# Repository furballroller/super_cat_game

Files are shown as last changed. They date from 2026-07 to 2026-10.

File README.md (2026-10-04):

# super_cat_game

> [!CAUTION]
> The current hardware version is [hardware_v1](hardware_v1)!! Anyway, is my first PCB project, so neither version is very good. It may be cost-inefficient and buggy.

> [!WARNING]
> **if regenerating production files from KICAD, the LCSC Part # in the BOM and component orientations in CPL may be incorrect. Make sure to double check part numbers and orientation in JLCPCB before paying** I don't know how to fix it and had to directly edit BOM.csv :<

> [!TIP]
> these banners are so cool lol

_Final product:_

- [_3D-printed case on Onshape_](https://cad.onshape.com/documents/4ded436d6b7f683e9c68b6fa/w/fe5cc562122e090332767be7/e/b2ba9b935da609d900851709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) (proper assembly instructions below)
- [_KiCAD Project_](hardware_v1)
- [_Arduino Sketches_](software) (PlatformIO IDE)

A5 - 1 (1)

Cat silhouette traced from this photo: ID <a href="https://www.dreamstime.com/cat-mid-air-jump-white-coloured-patches-jumping-down-against-yellow-wall-image115652480">115652480</a> @ <a href="https://www.dreamstime.com/lazaroctavian_info">Octavian Mihai Lazar</a> | <a href="https://www.dreamstime.com/">Dreamstime.com</a>

## backstory

So basically my friend had a cat, and I was just getting into arduino electronics, so I wanted to make a chasing game for the both of them! I ended up deciding on a pressure-sensitive LED mat, for an interactive laser-pointer kind-of game, with wifi connectivity for convenience. It could be nice to use regularly to keep your pets fit, but really this is just a fun beginner project to me.

Then, in between reels, I discovered Fallout, a 2026 hardware hackathon for 13-18yos backed by Hack Club. I was drawn in by the promise of full project funding and a free trip to Shenzhen, and was enthralled by the experienced and helpful community ready to help. I would highly recommend Hack Club hackathons like this if you're new/intermediate like me and within the age range :>

The scope expanded when I realised that there's so much more potential with my setup! I used a powerful ESP32 S3 N16R8 Devkit, so I broke out the pins for prototyping. You can hook up any peripherals you want for your game! Like, with a [3D printed kibble dispenser](https://electronoobs.com/tutorial/3d-printed-arduino-cat-feeder), you could implement scheduled feeding and dispense treats as an in-game currency :>

But you can program anything, not just for a cat! Chess online/locally would be easy and super fun! Maybe even something like [Osu](https://osu.ppy.sh/), make use of the full spectrum of colours! You might even want to host an online multiplayer game...

## overview

This project hardwires a pressure-sensitive LED mat to a powerful general-purpose devkit, intended for making inuitive arcade-style games (for a cat, if you'd like! :> )

I used Arduino to code up a simple cat game ([Arduino sketch](software/cat_game)), where a laser dot darts around, avoids people, and resets the game when caught. To use this, just upload the code to the devkit (using it's built-in USB-C port), plug it into the PCB, then plug the PCB into the wall!

The devkit opens the project to endless posibilities, including bluetooth game controllers, network games, and over-the-air coding for easy game dev ([template Arduino sketch with ArduinoOTA](software/template+OTA)). This project is meant to function as a very cool extension of the microcontroller, for those who might want to jump straight into making games using this touch interface.

### specs

- ~45*45cm play area
  - 14*14 Velostat pressure sensor matrix
  - 13*13 WS2812B LED matrix (very low resolution tho)
- Wifi/Bluetooth capability
  - Cheap ESP32 S3 N16R8 Devkit clone off [AliExpress](https://www.aliexpress.com/item/1005008790513258.html)
- Broken-out devkit pins and 5V power supply for any peripherals you might like to add
  - e.g. [3D printed kibble dispenser](https://electronoobs.com/tutorial/3d-printed-arduino-cat-feeder)

### cost

[Overall BOM.csv](bom.csv) | [PCB BOM.csv](hardware_v1/production/bom.csv)

The overall BOM represents what I plan to order: 5 populated PCB boards (JLCPCB minimum order quantity), but only 1 housing/mat/devkit. Though, I did include a laptop charger and the LED strips that I already have. This comes out to 111.83 USD.

I didn't include tools (not consumed) like soldering equipment and a 3D printer, but I did approximate the cost of consumables like solder, tape rolls, screws and filament.

#### Per unit

|Cost (USD)|Stuff|
|--|--|
|14.11|Power supply|
|22.15|Electronics|
|2.32|Housing|
|33.32|Mat|

Excluding shipping, it's about 71.90 USD per unit.

<!--
## big_picture
the mat should roll up

-->

### hardware

<!-- a flowchart -->


I decided to use a USBC PD laptop charger as the PSU since it's quite common and versatile and it's not too expensive.

The velostat matrix is connected with two 45cm lengths of 16-way IDC cables (not shown in CAD). One individual line will be cut, stripped, and stuck to the sensor lines at regular intervals along the mat, 14 horizontally and 14 vertically. There's more detail in the assembly walkthrough below.

#### Velostat pressure sensor matrix

The rest of the system is quite self-explanatory except for the Velostat pressure sensor matrix, so I'll try my best to explain. There's a good video of it by [MarcoReps on YouTube](https://www.youtube.com/watch?v=0uPZwMg5B3k).

Velostat is a thin plastic sheet with electrical resistance that decreases as it is pressed or deformed.

Each "sensor" works by sandwiching a square of Velostat between perpendicular strips of conductive fabric tape, such that it acts as a resistor between them.

velostat sensor

When the Velostat is compressed, the resistance between the two strips decreases. Connecting one tape to 3.3V through a normal resistor (e.g. 10k Ohms) and the other to GND, the circuit becomes a voltage divider between the Velostat and the normal resistor. The microcontroller can read the voltage at this point (relative to GND) to figure out the resistance of the Velostat, which tells you approximately how much pressure is on it!

circuit

Along one long conductive strip, multiple perpendicular strips can be laid across with Velostat between, creating a line of sensors. By connecting all the perpendicular lines to a multiplexer's channels, they are all left in a high-impedance state except the selected channel. The normal resistor and ADC pin can be connected on the single output of the multiplexer, so they can be reused when the channel is switched.

Conventional diagram



Another way to show the same circuit:



The matrix in the mat is 14 conductive lines crossed with 14 perpendicular lines, making a total of 14^2=196 "sensors." It's the same as the line of sensors, but there are multiple lines of sensors, with one ground connection each. The ground connections are controlled by another multiplexer, only allowing one line to be active at once.



This is a 4 by 4 example. Multiplexer 1 picks the line of sensors connected to GND, and multiplexer 2 picks the sensor from that line to read.

The real mat works using two 16 channel multiplexers (CD74HC4067) on the PCB: the ESP32 specifies a channel, the multiplexers switch to the corresponding Velostat sensor, then the ESP32 takes a reading through it's ADC pin. Instead of the normal resistor, there is a potentiometer (variable resistor) that allows you to adjust sensitivity.



This is how the sensors are tiled

### code

[My example sketches:](software) (currently untested)

- [press_light](software/press_light): intended to be a test of function, that should simply light up LEDs around where you press. This would be great for making sure the hardware is behaving, or as a fun starting point if you want to experiment with code and get the hang of Arduino.
- [cat_game](software/cat_game): a simple cat game where the computer controls a red laser-pointer-like dot to avoid people.
- [template](software/template): an empty template for your project! I set up some useful functions in functions.cpp and put all the initialisation code in for you.
- [template+OTA](software/template+OTA): same as [template](software/template), but I also set up [ArduinoOTA](https://github.com/JAndrassy/ArduinoOTA). I think it's really cool that you can upload code wirelesly like magic! ([a cool tutorial page](https://www.programmingelectronics.com/arduinoota/))

I used PlatformIO on Visual Studio Code to write my Arduino programs for the microcontroller. This may sound convoluted, but I did it this way because Arduino programs are easy to write (compared to industrial languages) but Arduino IDE is horrible!

If you want to use Arduino IDE, you can quite easily copy-paste my code into the IDE. For a given project folder in [software](software), you just kinda paste the stuff from functions.cpp first, then the stuff from main.cpp... it may take a bit of fiddling around though, so I would recommend looking into PlatformIO (after getting used to it, I find it way way better :>)

I used [FastLED](https://github.com/fastled/fastled) to control the WS2812B neopixels

## assembly

assembly image

<!-- <img width="360" height="360" alt="image" src="https://github.com/user-attachments/assets/02625bfc-674e-4e6e-94d2-2b4add3a4ae9" />   -->

I thought it was cool to include the little thumb, and the vents are accurate too! They're like LHS/RHS prints from a cat grabbing the case or something :>
Also, the USB port is on a 45 degree angle so the wire leaves perpendicular to the mat.

I'll touch on the key features of the design below. For more info, see the 3D model for this is in [my Onshape doc](https://cad.onshape.com/documents/4ded436d6b7f683e9c68b6fa/w/fe5cc562122e090332767be7/e/b2ba9b935da609d900851709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), under the tab "boxV1"
(my bad for the bad organisation, I'm still learning CAD)  

If you want to change the tolerances (they're untested), I haven't tried, sorry if something is inaccurate. It may be best to change the tolerances in your slicer.
> [!TIP]
> the Onshape link might not work. I had to click it, then **Ctrl+X Ctrl+V Enter** from the address bar

### electronics

I contained the circuit in a PCB attached to the corner of the mat, and I've also desgined a 3D-printed housing for it.

The whole project runs off an ESP32 S3 N16R8 microcontroller devkit, which is like an Arduino but better (in my opinion)

[On Aliexpress](https://www.aliexpress.com/item/1005008790513258.html)
(**I would recommend getting "S3 KIT" because the screw terminals are very handy, but I put the board by itself into the BOM**)

When choosing a microcontroller, I noticed that a lot of clone (knockoff) ESP32 S3 devkits, including the one I bought, have the antenna port but also an antenna built into the PCB. I think they give you the option to change to an external antenna by doing a bit of soldering, but by default it is connected to the onboard antenna.

#### PCB

PCB preview
<!-- <img width="360" height="360" alt="PCB" src="" />   -->

> [!CAUTION]
>
> - Ignore the capacitor going off the edge, the EasyEDA model is wrong
> - The two parallel rows of vertical pin headers (for the devkit) should be female, again the EasyEDA model is wrong

PCB

schematic

About the design:

- JL1 and JR1 hold the ESP32 devkit
- The USB-C is for power only
- JLED1 is for the LED strip
- JPWR1 is 5V power for any peripherals you might want to add
- The IDC sockets are for the pressure-sensing data lines
- The fancy ICs are just CD74HC4067 multiplexers for selecting the pressure-sensing channel to read
- The potentiometer is for adjusting the sensitivity of the pressure sensing (it's part of a voltage divider)
- U1 is a logic level converter for the LEDs.

Regarding soldering: I designed the PCB to be hand-soldered, hence the abundance of THT and the large 0805 capacitors/resistors. My only concerns are the SSOP 74HC4067 and 6-pin USB-C port, but other than that the rest should be beginner friendly, from what I can gather. I'm thinking of going to my local makerspace to solder this. In Melbourne, Library at the Dock has one equipped with a digital microscope, flux/solder/wick, and  Hakko FX-888 soldering stations, all free of charge. Maybe be careful around ESD, I'll update on my degree of success when I build it.

#### housing

housing
<!-- <img width="412" height="319" alt="housing" src="https://github.com/user-attachments/assets/c8540786-b5d8-4412-b8d4-58c8dfad0934" /> -->

I'm not very good at 3D CAD either, but this should work... I think  
The design is quite self-explanatory, but below are some key features that I thought I should highlight:

bottom of base  

On the base, there is a cutout for those holes on the mat. The holes are truncated cones, inspired by [this video by BV3D](https://youtu.be/zaphoWIwSGI). 
I designed my case to work with 3M screws, and the truncated cones means you can use machine screws or self-tapping (I think)

top of base  
top of base, PCB overlaid  

The base supports the PCB with a few stilts through the holes in the PCB, again using M3 truncated cones. The smaller stilts give some support to the IDC connectors, which I expect may require some force to plug in and out.

top  
  

The top fits on the bottom with M3 screws, and features holes for IDC, the LED strip, the USB-C power port, optional 5V power lines, and the broken-out GPIO from the devkit. Also there are (very stylish) vents :>

lid  
  

There's also a lid that slides onto the top, so the devkit is protected but can be accessed easily during game development. 
I included a cool thinner section where the onboard LED is, so the status light should look like a cat's paw.

### sensor_mat

> [!TIP]
> You'll see two holes in the top-right corner of the mat. These fit M3 screw heads, and should help anchor the PCB to the mat.

1. The LED strips
LED strips assembled  

I used 13 LED long sections of 30 LED/m WS2812B individually addressable LEDs
With pads on either side, each section is about 43.333mm long (theoretically)  
[Similar product on AliExpress](https://www.aliexpress.com/item/1005007989207832.html)
(**MAKE SURE THE SPACING IS 30 LEDs/m; I'd recommend buying 2 "3m 30 IP30"**)

There are 13 of these sections, forming a 13*13 grid (169 LEDs)
The ends can be soldered together with jumper wires, preferably with stranded wire, like so:

<figure>
	Suggested LED strip interconnection
	Suggested fold to connect to PCB  
	<figcaption>(don't crease too much tho!)</figcaption>
</figure>

2. The popsicle sticks  

Popsicle sticks assembled  

I used 2mm thick, 18mm wide popsicle sticks (jumbo craft sticks)  
[My local option (Australia)](https://www.officeworks.com.au/shop/officeworks/p/kadink-jumbo-craft-sticks-natural-50-pack-showk0137)

In the CAD, I made very long, 18mm-wide rectangles for simplicity. 
They represent the area that should be filled with popsicle sticks. 
It may be useful to trim off the rounded ends for a fuller surface, but the space could alternatively be filled with hot glue for better adhesion.

They will be adhered together with the conductive tape that goes on top (see below). 
They should be adhered to the LED strip with high-temperature hot glue or silicone (not being lazy! it's good for sticking to wood and flex-PCB, trust). 
Please ensure hot glue doesn't get under the popsicle sticks, as this may affect the pressure detection and make the mat lumpy. 

<figure>  
	Where to smush the glue 
	<figcaption>Try smushing the glue into the corner where the edge of the popsicle sticks meets the LED's flex-PCB</figcaption>
</figure>

3. Conductive fabric tape (bottom)  

Conductive fabric tape (bottom) assembled

I used 0.1mm thick, 8mm wide conductive fabric tape. This acts as the bottom layer of the velostat matrix.  
[Similar product on AliExpress](https://www.aliexpress.com/item/1005007568611729.html)  
(**I'd recommend buying 1 "8mm"**)

The tape sticks onto the wood to connect it together. If this isn't sturdy enough, the sticks can keep their rounded ends, and hot glue can help hold them together (in the gap made by the rounded ends)

An IDC wire needs to be attached to one end of each strip, so I recommend the following:

Leave a 1-2cm tape overhang  

Leave a 1-2cm tape overhang

Press the stripped IDC wire here  

Peel the stripped IDC wire away from the rest and press it here. for extra security, you could wrap the tape around the entire row of IDC wires.

super cat game (6)  

Press another section of tape here, sticking the sticky sides together and securing the wire's insulation and popsicle stick together

super cat game (7)  

Wrap the main tape over the other strip and the wire (ensure it has contact with both the insulation and the bare metal, and press it into the crevices and flush to the bottom of the mat

4. Velostat

Velostat assembled  

I used a 0.1mm thick, 280mm square sheet of velostat, cut up into ~18mm squares (this stuff is expensive!!)  
[My local option (Australia)](https://www.pakronics.com.au/products/pressure-sensitive-conductive-sheet-velostat-linqstat-ada1361)

The squares will be adhered to the popsicles with thin-film double-sided tape, with two 4mm wide sections flanking the conductive tape running down the middle of the popsicles.

It is important that the tape is as thin or thinner than the velostat (≤0.1mm), or it may squish instead of the velostat, lowering the sensitivity, and so resolution, of pressure readings.

[Double-sided tape on AliExpress](https://www.aliexpress.com/item/1005012157309588.html)  
(**I'd recommend buying 1 "5mm"**)

5. Conductive fabric tape (top)

Conductive fabric tape (top) assembled  

This layer is sticky-side-up, so in real life you would stick it onto the top EVA first (see below). Please make sure the tape is aligned such that it doesn't touch the bottom layer directly anywhere, only conducting through the Velostat squares.

An IDC wire needs to be attached just like in the other layer, so I would recommend the same strategy, but wrapped upwards around the EVA. The ugly tape overhangs on top of the EVA will be covered by electrical tape later.

6. Frosted plastic sheet (EVA)

  

I used a ~1mm thick, 450mm square of EVA plastic intended to line drawers.  
[My local option (Australia)](https://www.rejectshop.com.au/p/drawer-and-shelf-liner-45x150cm)

The top layer of conductive tape should be stuck to the bottom of this sheet, on the smooth side. This EVA layer can be adhered to the bottom construction with electrical tape, not just because it's easy to design, but because of it's suitable properties. The mat is designed to loosely roll up for easy transport/storage, requiring flexibility, and the edges must be soft to keep flying fingers/paws safe around the mat :)

## the_past

V0 3D

V0 PCB

V0 sch

> [!CAUTION]
> I cobbled V0 together from backups so maybe double check whether it works if you plan to build it. e.g. there's no copper exclusion around the antenna :<

Just a quick note about the [hardware_v0](hardware_v0) and [hardware_v1](hardware_v1), I just uploaded v0 so you can see a previous design I made. I wanted to preserve more ESP32 GPIO pins, so I used counter ICs to cycle through the MUX channels of the sensor grid. This would've allowed me to step through each channel with just one clock pin per counter, compared to the 4 pins per counter I would've needed to control the MUX channel directly. It wouldn't have added much time either, as the counter works even faster than a digitalWrite()! Sending one clock pulse might even be more efficient than using Arduino to update the state of 4 pins... anyway, I decided to remove the counters in V1 to save board space and money, seeing as there are so many available GPIO anyway lol :>

## the_future

Some ideas I have:

- multiplexing/charlieplexing/shift registers with regular LEDs to replace expensive neopixels
- using an ESP32 S3 WROOM SOC module for a smaller and cheaper PCB
- using a library like NeoPixelBus instead of FastLED to make the Arduino code faster/efficient
- somehow allowing IDC to attach/detatch without needing to unscrew the lid, for portability/storage

Lemme know if you've got any suggestions!
My email: [aydeny8k@gmail.com](mailto:aydeny8k@gmail.com)

## references

The Velostat pressure matrix idea: [Youtube video by MarcoReps](https://www.youtube.com/watch?v=0uPZwMg5B3k)

Truncated-cone screw holes idea: [Youtube video by BV3D](https://youtu.be/zaphoWIwSGI)

Sliding lid shape: [Wuodan0 on Thingiverse](https://www.thingiverse.com/thing:5201077)

[FastLED](https://github.com/fastled/fastled) Arduino library

[ArduinoOTA](https://github.com/JAndrassy/ArduinoOTA) Arduino library

[easyeda2kicad.py](https://github.com/uPesy/easyeda2kicad.py) Python script

Pictures annotated in Google Drawings

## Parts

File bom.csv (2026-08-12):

Name | Description | Link | Cost (USD)
5x PCB | Cost of 5 boards from JLCPCB |  | 5.20
5x PCB components | Cost of components for 5 boards from LCSC |  | 24.72
ESP32 S3 devkit | ESP32 S3 N16R8 devkit | https://www.aliexpress.com/item/1005008790513258.html | 7.25
Solder | 15g lead-free solder 0.71mm | https://www.jaycar.com.au/1-0mm-15g-lead-free-solder-hobby-tube/p/NS3092 | 4.23
2x IDC socket | 2x 16-way IDC line socket | https://www.jaycar.com.au/16-way-idc-line-socket/p/PS0985 | 2.75
1m IDC cable | 1m 16-way IDC cable | https://www.jaycar.com.au/16-way-idc-ribbon-cable/p/WM4502 | 1.94
9x 6mm M3 screws | Approximately 0.10 USD each |  | 0.90
3D printer filament | 71g per housing of PLA, approximately 0.02 USD/g |  | 1.42
Neopixel LEDs | 2x 3m sections of 30 LED/m strip, total 180 LEDs | https://www.aliexpress.com/item/1005007989207832.html | 11.86
2m power wire | 2m 7.5A hook-up wire | https://www.jaycar.com.au/7-5a-heavy-duty-hook-up-wire-black/p/WH3041 | 0.99
Popsicle sticks | 50 Jumbo Craft Sticks | https://www.officeworks.com.au/shop/officeworks/p/kadink-jumbo-craft-sticks-natural-50-pack-showk0137 | 2.12
Conductive tape | 10m roll of 8mm conductive fabric tape | https://www.aliexpress.com/item/1005007568611729.html | 3.81
Velostat sheet | 28x28cm sheet of velostat | https://www.pakronics.com.au/products/pressure-sensitive-conductive-sheet-velostat-linqstat-ada1361 | 8.28
Double sided tape | 50m roll of 5mm double-sided PET tape | https://www.aliexpress.com/item/1005012157309588.html | 4.25
Frosted plastic sheet | 45*150cm EVA plastic sheet intended to line drawers | https://www.rejectshop.com.au/p/drawer-and-shelf-liner-45x150cm | 3.00
5V 3A Power supply | 65W USBC PD Laptop charger | https://www.amazon.com.au/Charger-Universal-Chromebook-Adapter-Compatible/dp/B0F4MJYQH7/ | 14.11
Estimated shipping | Generous estimate of JLCPCB and LCSC combined |  | 15.00
 |  |  | 111.83

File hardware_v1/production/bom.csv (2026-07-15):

Designator | Footprint | Quantity | Value | LCSC Part #
C1, C2, C3, C4, C9 | 0805 | 5 | 100n | C28233
C5 | cap_flat | 1 | 1000u | C439782
J1 | HDR-TH_28P-P2.54-H-M-R2-C14-S2.54 | 1 | Conn_02x14_Odd_Even | C725926
JA1, JB1 | IDC-TH_16P-P2.54_C3406 | 2 | Conn_02x08_Odd_Even | C3406
JL1, JR1 | HDR-TH_22P-P2.54-V-M | 2 | FH2.54-09-22PZD | C7500786
JLED1 | CONN-TH_3P-P2.54_KF128-2.54-3P | 1 | Screw_Terminal_01x03 | C474921
JPWR1 | CONN-TH_P2.54_KF128-2.54-2P | 1 | KF128-2.54-2P | C474920
R1, R2 | 0805 | 2 | 5.1K | C27834
R3 | 0805 | 1 | 330 | C17630
R4 | 0805 | 1 | 3.3k | C26020
RV1 | RES-ADJ-TH_3P-L7.1-W6.9-P2.50-L_3362P | 1 | 3362P-1-203_C118933 | C338758
U1 | SOT-23-5_HandSoldering | 1 | SN74LV1T34DBV | C100024
UA2, UB2 | SSOP-24_L8.1-W5.3-P0.65-LS7.8-BL | 2 | CD74HC4067SM96 | C98457
USB1 | TYPE-C-SMD_TYPE-C-6P_1 | 1 | TYPE-C 6P | C456012

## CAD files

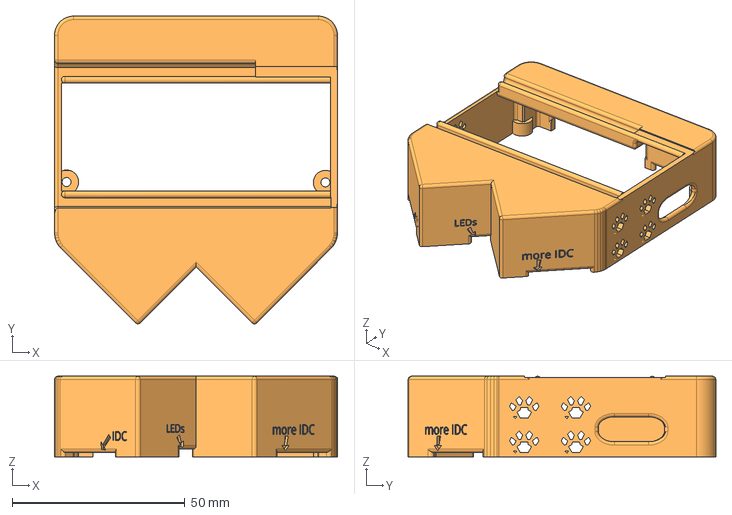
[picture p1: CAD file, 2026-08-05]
3D_files/boxV1 - Top.step
82.0 x 89.2 x 23.3 mm

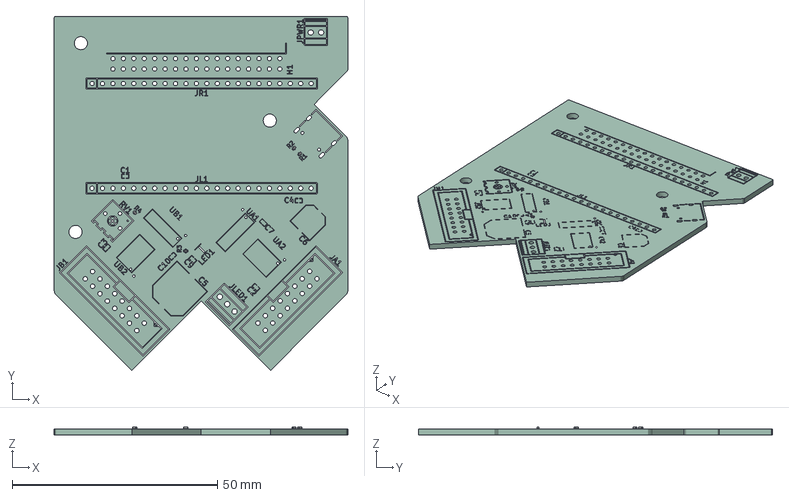
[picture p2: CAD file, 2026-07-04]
kicad-project/.step
71.5 x 86.2 x 1.94 mm
R_0402_1005Metric x 4
pressure_sense_silkscreen
pressure_sense_PCB

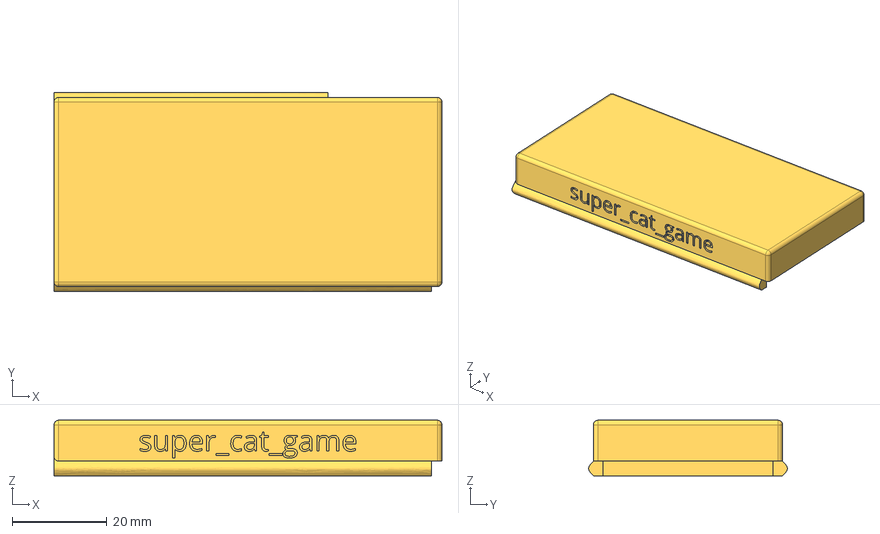
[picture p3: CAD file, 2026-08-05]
3D_files/boxV1 - Lid.step
82.0 x 42.0 x 11.7 mm

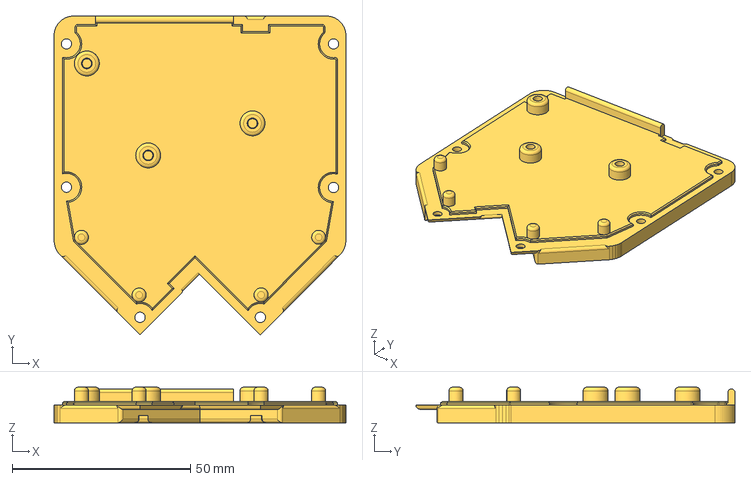
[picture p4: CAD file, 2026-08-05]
3D_files/boxV1 - Bottom.step
82.0 x 89.6 x 10.0 mm

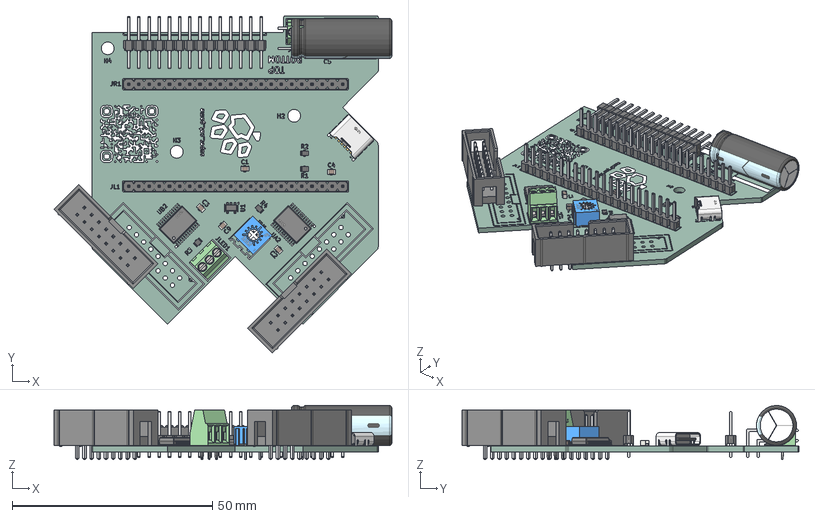
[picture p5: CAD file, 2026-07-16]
3D_files/boardV1.step
84.3 x 84.1 x 13.5 mm
R_0805_2012Metric x 4
C_0805_2012Metric x 5
HDR-TH_22P-P2.54-M-LI-1X22P x 2
HDR-TH_28P-P2.54-M-WI-2X14P
CONN-TH_P2.54_KF128-2.54-2P
SOT-23-5
IDC-TH_16P-P2.54-V-R2-C8-S2.54 x 2
CAP-TH_BD10.0-P5.00-D0.6-FD
SSOP-24_L8.2-W5.3-H1.8-LS7.8-P0.65 x 2
TYPE-C-SMD_6P-L8.9-W6.8-H3.2-P1.00
CONN-TH_3P-P2.54_KF128-2.54-3P
RES-ADJ-TH_3362P
pressure_sense_silkscreen x 2
pressure_sense_PCB

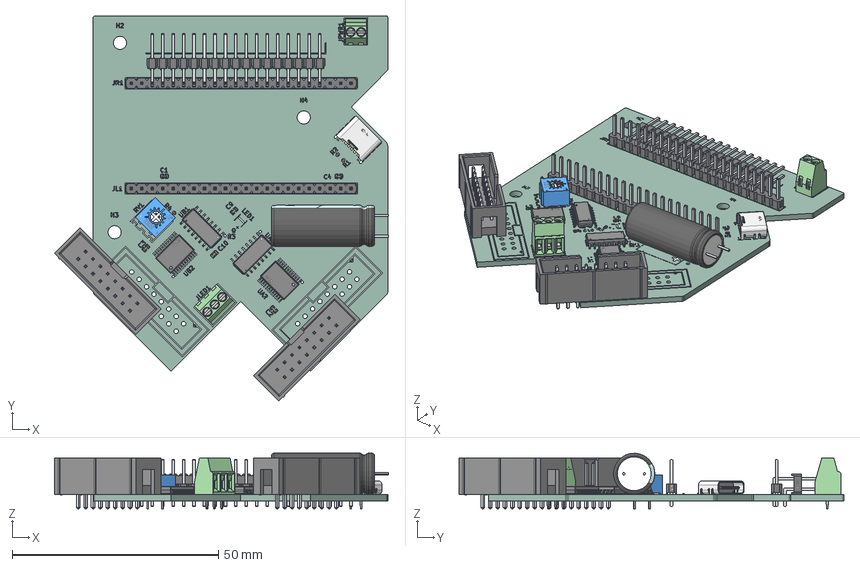
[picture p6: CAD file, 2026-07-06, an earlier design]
3D_files/boardV0.step
81.0 x 93.4 x 13.5 mm
C0402_L1.0-W0.5-H0.5 x 7
HDR-TH_22P-P2.54-M-LI-1X22P x 2
SOIC-16_L9.9-W3.9-H1.8-LS6.0-P1.27 x 2
R_0402_1005Metric x 4
CONN-TH_P2.54_KF128-2.54-2P
IDC-TH_16P-P2.54-V-R2-C8-S2.54 x 2
CAP-TH_BD10.0-P5.00-D0.6-FD
SSOP-24_L8.2-W5.3-H1.8-LS7.8-P0.65 x 2
RES-ADJ-TH_3362P
HDR-TH_34P-P2.54-M-WI-2X17P
TYPE-C-SMD_6P-L8.9-W6.8-H3.2-P1.00
CONN-TH_3P-P2.54_KF128-2.54-3P
pressure_sense_silkscreen
pressure_sense_PCB

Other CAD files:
3D_files/boxV1 - Bottom.stl
3D_files/boxV1 - Lid.stl
3D_files/boxV1 - Top.stl

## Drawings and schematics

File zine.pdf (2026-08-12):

# super_cat_game

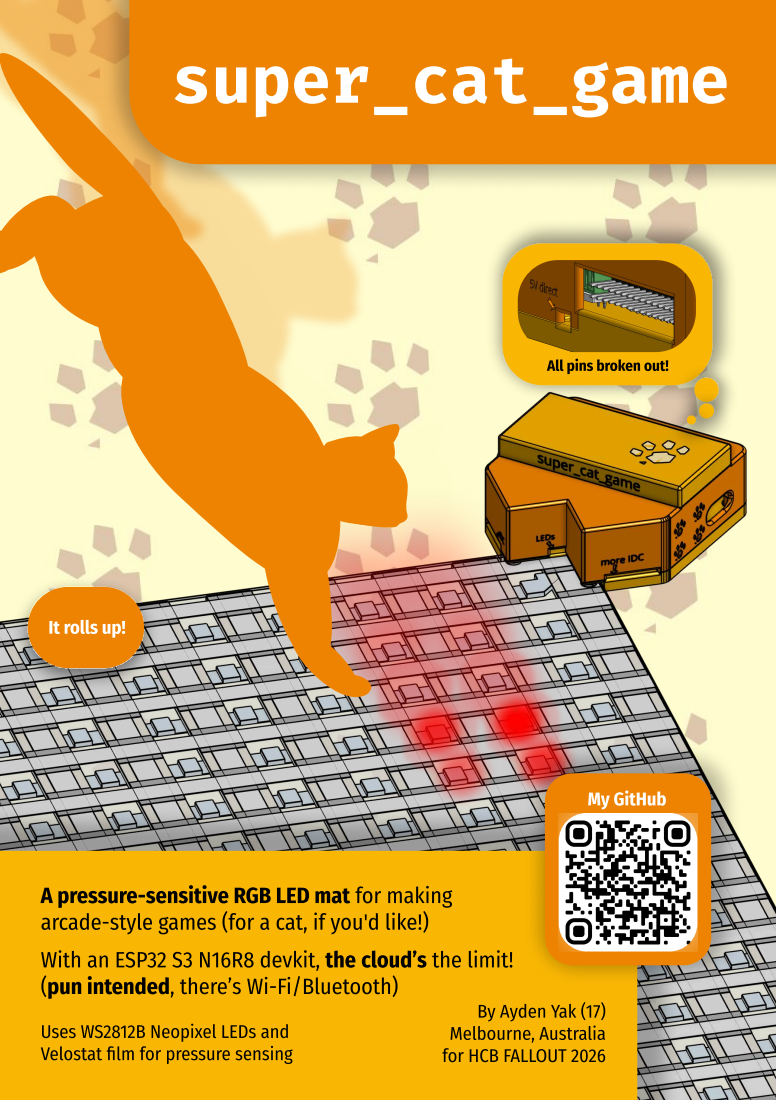
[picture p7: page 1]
My GitHub

All pins broken out!

It rolls up!

A pressure-sensitive RGB LED mat for making
arcade-style games (for a cat, if you'd like!)

With an ESP32 S3 N16R8 devkit, the cloud’s the limit!
(pun intended, there’s Wi-Fi/Bluetooth)

By Ayden Yak (17)

Uses WS2812B Neopixel LEDs and
Velostat film for pressure sensing

Melbourne, Australia
for HCB FALLOUT 2026

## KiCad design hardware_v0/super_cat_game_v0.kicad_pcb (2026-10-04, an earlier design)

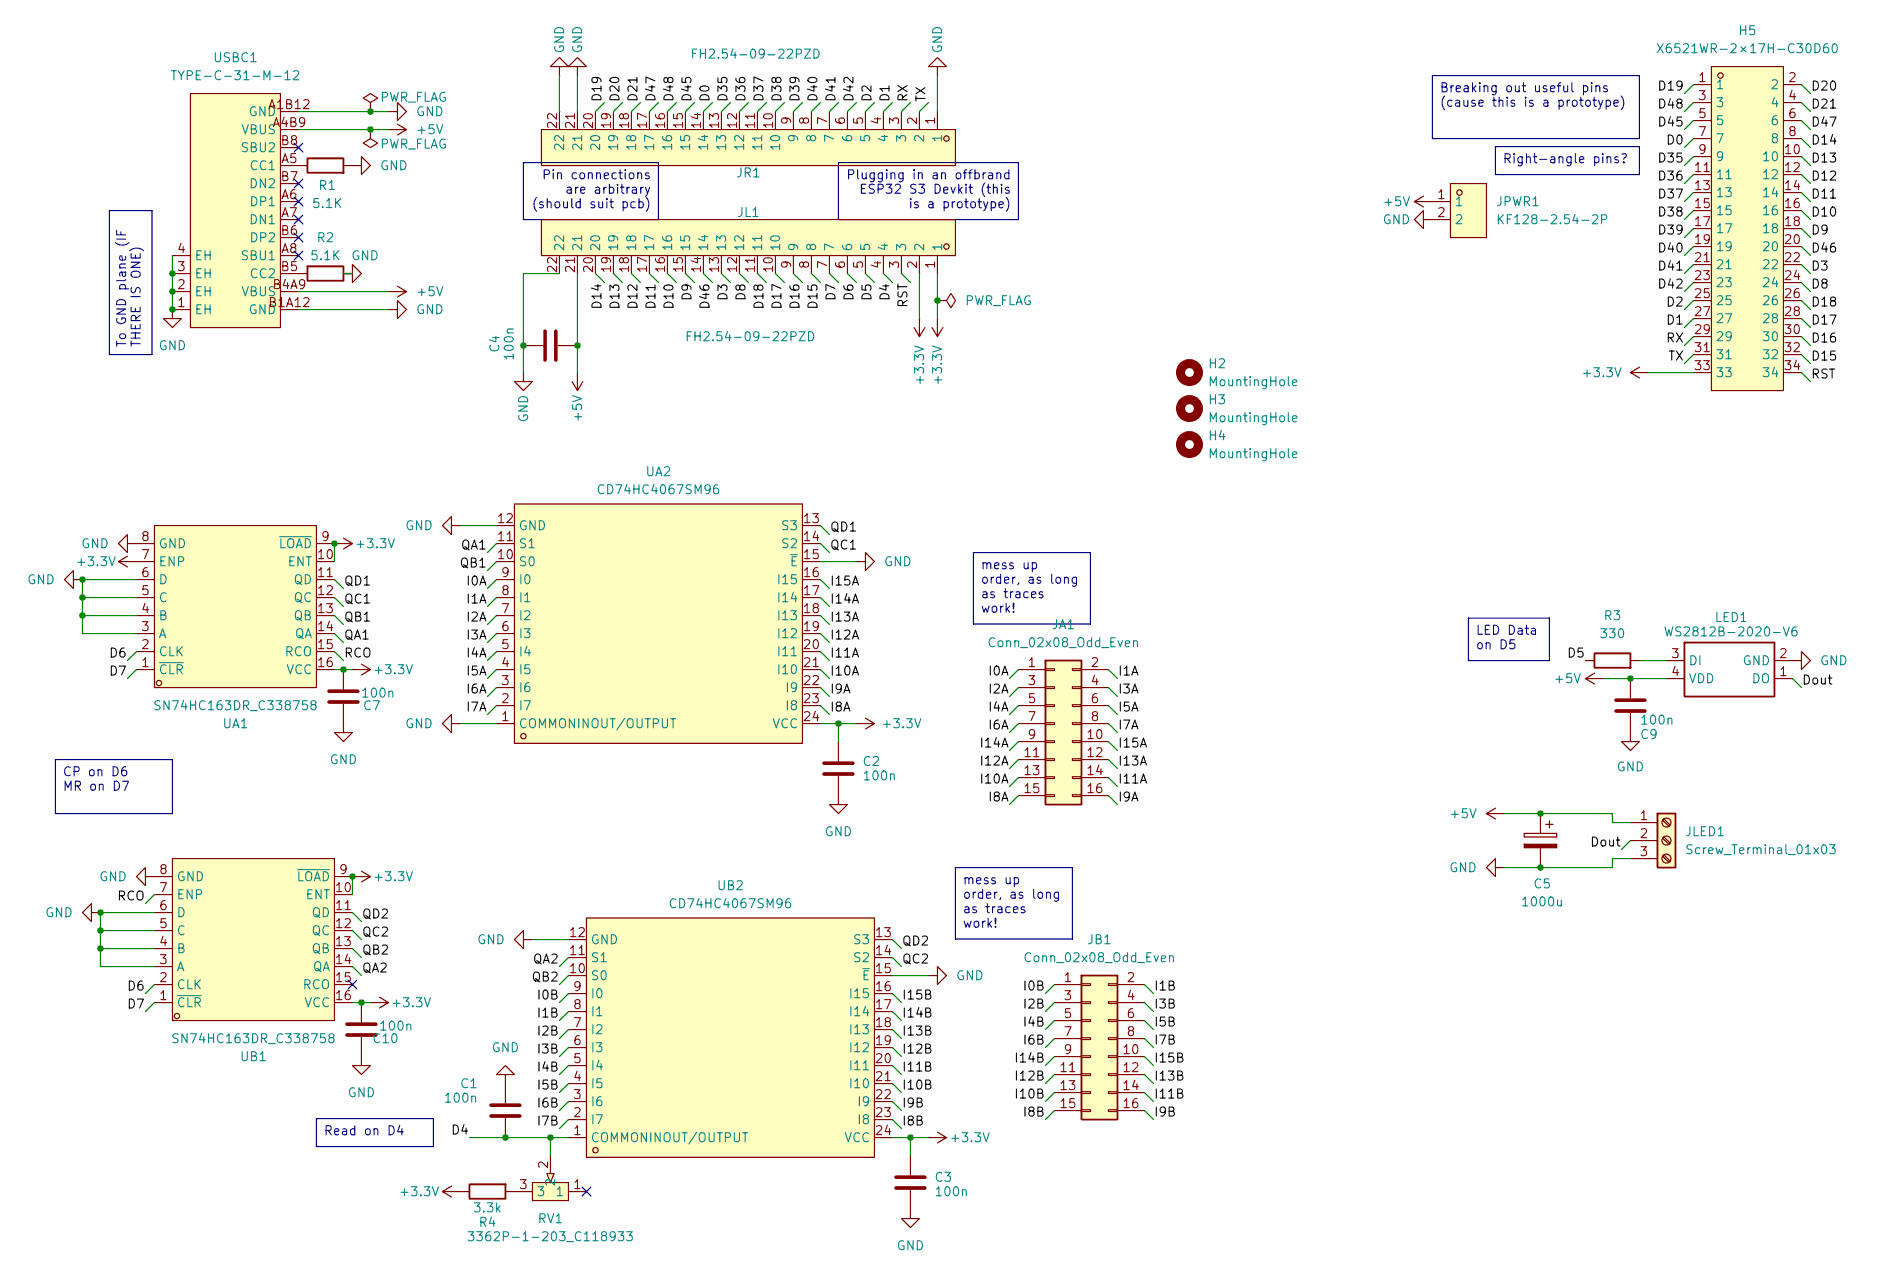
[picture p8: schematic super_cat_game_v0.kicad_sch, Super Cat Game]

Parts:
C1, C2, C3, C7, C9, C10: 100n; C0402; JLC_3DModel 32fe2cf9314f444ca2785a33c2db7189
C4: 100n; C0402; LCSC Part # C1525
C5: 1000u; CAP-TH_BD10.0-P5.00-D0.6-FD; JLC_3DModel fb7e59b4bf4a464e9052b6d7cde2fdda
H2, H3, H4: MountingHole; MountingHole_3.2mm_M3
H5: X6521WR-2×17H-C30D60; HDR-TH_34P-P2.54-H-M-R2-C17-S2.54; MPN X6521WR-2x17H-C60D30; LCSC Part # C725929
JA1: Conn_02x08_Odd_Even; IDC-TH_16P-P2.54_C3406; JLC_3DModel 20dc7cf4168b42d3ab78a2412575e9e9
JB1: Conn_02x08_Odd_Even; IDC-TH_16P-P2.54_C3406; JLC_3DModel 20dc7cf4168b42d3ab78a2412575e9e9
JL1: FH2.54-09-22PZD; HDR-TH_22P-P2.54-V-M; MPN FH2.54-09-22PZD; LCSC Part # C7500786
JLED1: Screw_Terminal_01x03; CONN-TH_3P-P2.54_KF128-2.54-3P; JLC_3DModel a3f15aa9d36b4fa2b870b9dbfce89390
JPWR1: KF128-2.54-2P; CONN-TH_P2.54_KF128-2.54-2P; MPN KF128-2.54-2P; LCSC Part # C474920
JR1: FH2.54-09-22PZD; HDR-TH_22P-P2.54-V-M; MPN FH2.54-09-22PZD; LCSC Part # C7500786
LED1: WS2812B-2020-V6; LED-SMD_4P-L2.2-W2.0-P1.00_WS2815C-2020-4P; Manufacturer Part WS2812B-2020-V6; LCSC Part # C52917434
R1, R2: 5.1K; R_0402_1005Metric; LCSC Part # C25905
R3: 330; R_0402_1005Metric; LCSC Part # C25104
R4: 3.3k; R_0402_1005Metric; LCSC Part # C25890
RV1: 3362P-1-203_C118933; RES-ADJ-TH_3P-L7.1-W6.9-P2.50-L_3362P; MPN 3362P-1-203; LCSC Part # C118933
UA1: SN74HC163DR_C338758; SOIC-16_L9.9-W3.9-P1.27-LS6.0-BL; MPN SN74HC163DR; LCSC Part # C338758
UA2: CD74HC4067SM96; SSOP-24_L8.1-W5.3-P0.65-LS7.8-BL; MPN CD74HC4067SM96; LCSC Part # C98457
UB1: SN74HC163DR_C338758; SOIC-16_L9.9-W3.9-P1.27-LS6.0-BL; MPN SN74HC163DR; LCSC Part # C338758
UB2: CD74HC4067SM96; SSOP-24_L8.1-W5.3-P0.65-LS7.8-BL; MPN CD74HC4067SM96; LCSC Part # C98457
USBC1: TYPE-C-31-M-12; USB-C_SMD-TYPE-C-31-M-12_1; MPN TYPE-C-31-M-12; LCSC Part # C165948

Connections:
+3.3V: C2.1, C3.1, C7.1, C10.1, H5.33, JL1.1, JL1.2, R4.1, UA1.7 (ENP), UA1.9 (~LOAD), UA1.10 (ENT), UA1.16 (VCC), UA2.24 (VCC), UB1.9 (~LOAD), UB1.10 (ENT), UB1.16 (VCC), UB2.24 (VCC)
+5V: C4.2, C5.1, C9.1, JL1.21, JLED1.1, JPWR1.1, LED1.4 (VDD), USBC1.A4B9 (VBUS), USBC1.B4A9 (VBUS)
/D0: H5.7, JR1.14
/D1: H5.27, JR1.4
/D2: H5.25, JR1.5
/D3: H5.22, JL1.13
/D4: C1.1, JL1.4, RV1.2, UB2.1 (COMMONINOUT/OUTPUT)
/D5: JL1.5, R3.1
/D6: JL1.6, UA1.2 (CLK), UB1.2 (CLK)
/D7: JL1.7, UA1.1 (~CLR), UB1.1 (~CLR)
/D8: H5.24, JL1.12
/D9: H5.18, JL1.15
/D10: H5.16, JL1.16
/D11: H5.14, JL1.17
/D12: H5.12, JL1.18
/D13: H5.10, JL1.19
/D14: H5.8, JL1.20
/D15: H5.32, JL1.8
/D16: H5.30, JL1.9
/D17: H5.28, JL1.10
/D18: H5.26, JL1.11
/D19: H5.1, JR1.20
/D20: H5.2, JR1.19
/D21: H5.4, JR1.18
/D35: H5.9, JR1.13
/D36: H5.11, JR1.12
/D37: H5.13, JR1.11
/D38: H5.15, JR1.10
/D39: H5.17, JR1.9
/D40: H5.19, JR1.8
/D41: H5.21, JR1.7
/D42: H5.23, JR1.6
/D45: H5.5, JR1.15
/D46: H5.20, JL1.14
/D47: H5.6, JR1.17
/D48: H5.3, JR1.16
/Dout: JLED1.2, LED1.1 (DO)
/I0A: JA1.1, UA2.9 (I0)
/I0B: JB1.1, UB2.9 (I0)
/I1A: JA1.2, UA2.8 (I1)
/I1B: JB1.2, UB2.8 (I1)
/I2A: JA1.3, UA2.7 (I2)
/I2B: JB1.3, UB2.7 (I2)
/I3A: JA1.4, UA2.6 (I3)
/I3B: JB1.4, UB2.6 (I3)
/I4A: JA1.5, UA2.5 (I4)
/I4B: JB1.5, UB2.5 (I4)
/I5A: JA1.6, UA2.4 (I5)
/I5B: JB1.6, UB2.4 (I5)
/I6A: JA1.7, UA2.3 (I6)
/I6B: JB1.7, UB2.3 (I6)
/I7A: JA1.8, UA2.2 (I7)
/I7B: JB1.8, UB2.2 (I7)
/I8A: JA1.15, UA2.23 (I8)
/I8B: JB1.15, UB2.23 (I8)
/I9A: JA1.16, UA2.22 (I9)
/I9B: JB1.16, UB2.22 (I9)
/I10A: JA1.13, UA2.21 (I10)
/I10B: JB1.13, UB2.21 (I10)
/I11A: JA1.14, UA2.20 (I11)
/I11B: JB1.14, UB2.20 (I11)
/I12A: JA1.11, UA2.19 (I12)
/I12B: JB1.11, UB2.19 (I12)
/I13A: JA1.12, UA2.18 (I13)
/I13B: JB1.12, UB2.18 (I13)
/I14A: JA1.9, UA2.17 (I14)
/I14B: JB1.9, UB2.17 (I14)
/I15A: JA1.10, UA2.16 (I15)
/I15B: JB1.10, UB2.16 (I15)
/QA1: UA1.14 (QA), UA2.11 (S1)
/QA2: UB1.14 (QA), UB2.11 (S1)
/QB1: UA1.13 (QB), UA2.10 (S0)
/QB2: UB1.13 (QB), UB2.10 (S0)
/QC1: UA1.12 (QC), UA2.14 (S2)
/QC2: UB1.12 (QC), UB2.14 (S2)
/QD1: UA1.11 (QD), UA2.13 (S3)
/QD2: UB1.11 (QD), UB2.13 (S3)
/RCO: UA1.15 (RCO), UB1.7 (ENP)
/RST: H5.34, JL1.3
/RX: H5.29, JR1.3
/TX: H5.31, JR1.2
GND: C1.2, C2.2, C3.2, C4.1, C5.2, C7.2, C9.2, C10.2, JL1.22, JLED1.3, JPWR1.2, JR1.1, JR1.21, JR1.22, LED1.2 (GND), R1.2, R2.1, UA1.3 (A), UA1.4 (B), UA1.5 (C), UA1.6 (D), UA1.8 (GND), UA2.1 (COMMONINOUT/OUTPUT), UA2.12 (GND), UA2.15 (~E), UB1.3 (A), UB1.4 (B), UB1.5 (C), UB1.6 (D), UB1.8 (GND), UB2.12 (GND), UB2.15 (~E), USBC1.1 (EH), USBC1.2 (EH), USBC1.3 (EH), USBC1.4 (EH), USBC1.A1B12 (GND), USBC1.B1A12 (GND)
unnamed: LED1.3 (DI), R3.2
unnamed: R4.2, RV1.3
unnamed: R1.1, USBC1.A5 (CC1)
unnamed: R2.2, USBC1.B5 (CC2)

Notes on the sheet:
Read on D4
To GND plane (IF THERE IS ONE)
mess up order, as long as traces work!
Breaking out useful pins (cause this is a prototype)
CP on D6 MR on D7
Right-angle pins?
Plugging in an offbrand ESP32 S3 Devkit (this is a prototype)
LED Data on D5
Pin connections are arbitrary (should suit pcb)

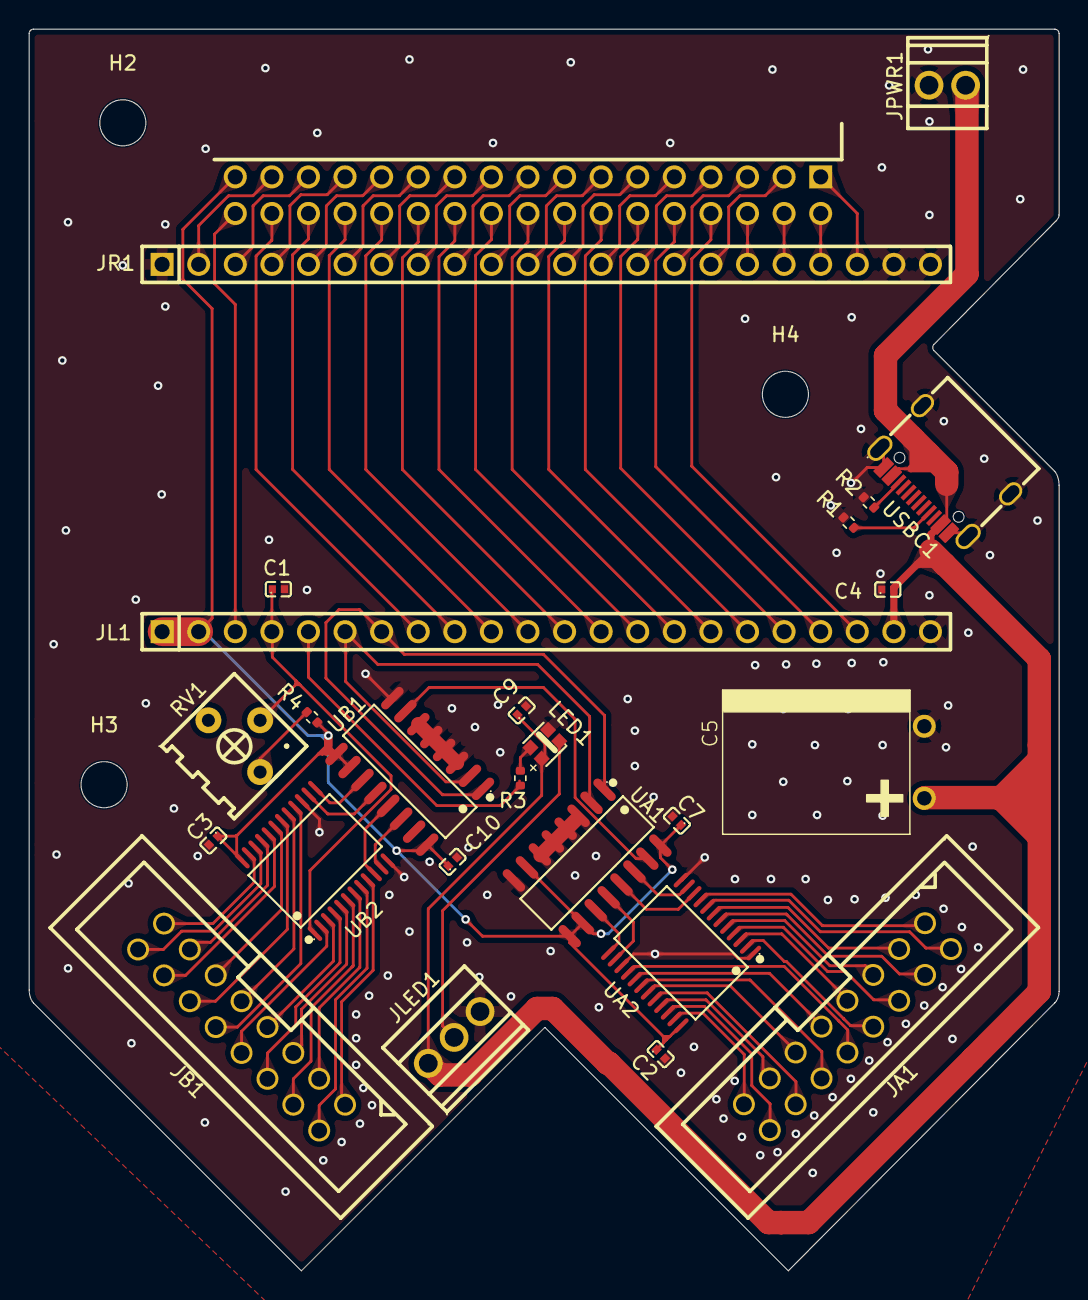
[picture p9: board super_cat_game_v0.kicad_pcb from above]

Board: 2 copper layers, 71.5 x 86.2 mm, 29 parts (0 on the bottom side), 86 nets.

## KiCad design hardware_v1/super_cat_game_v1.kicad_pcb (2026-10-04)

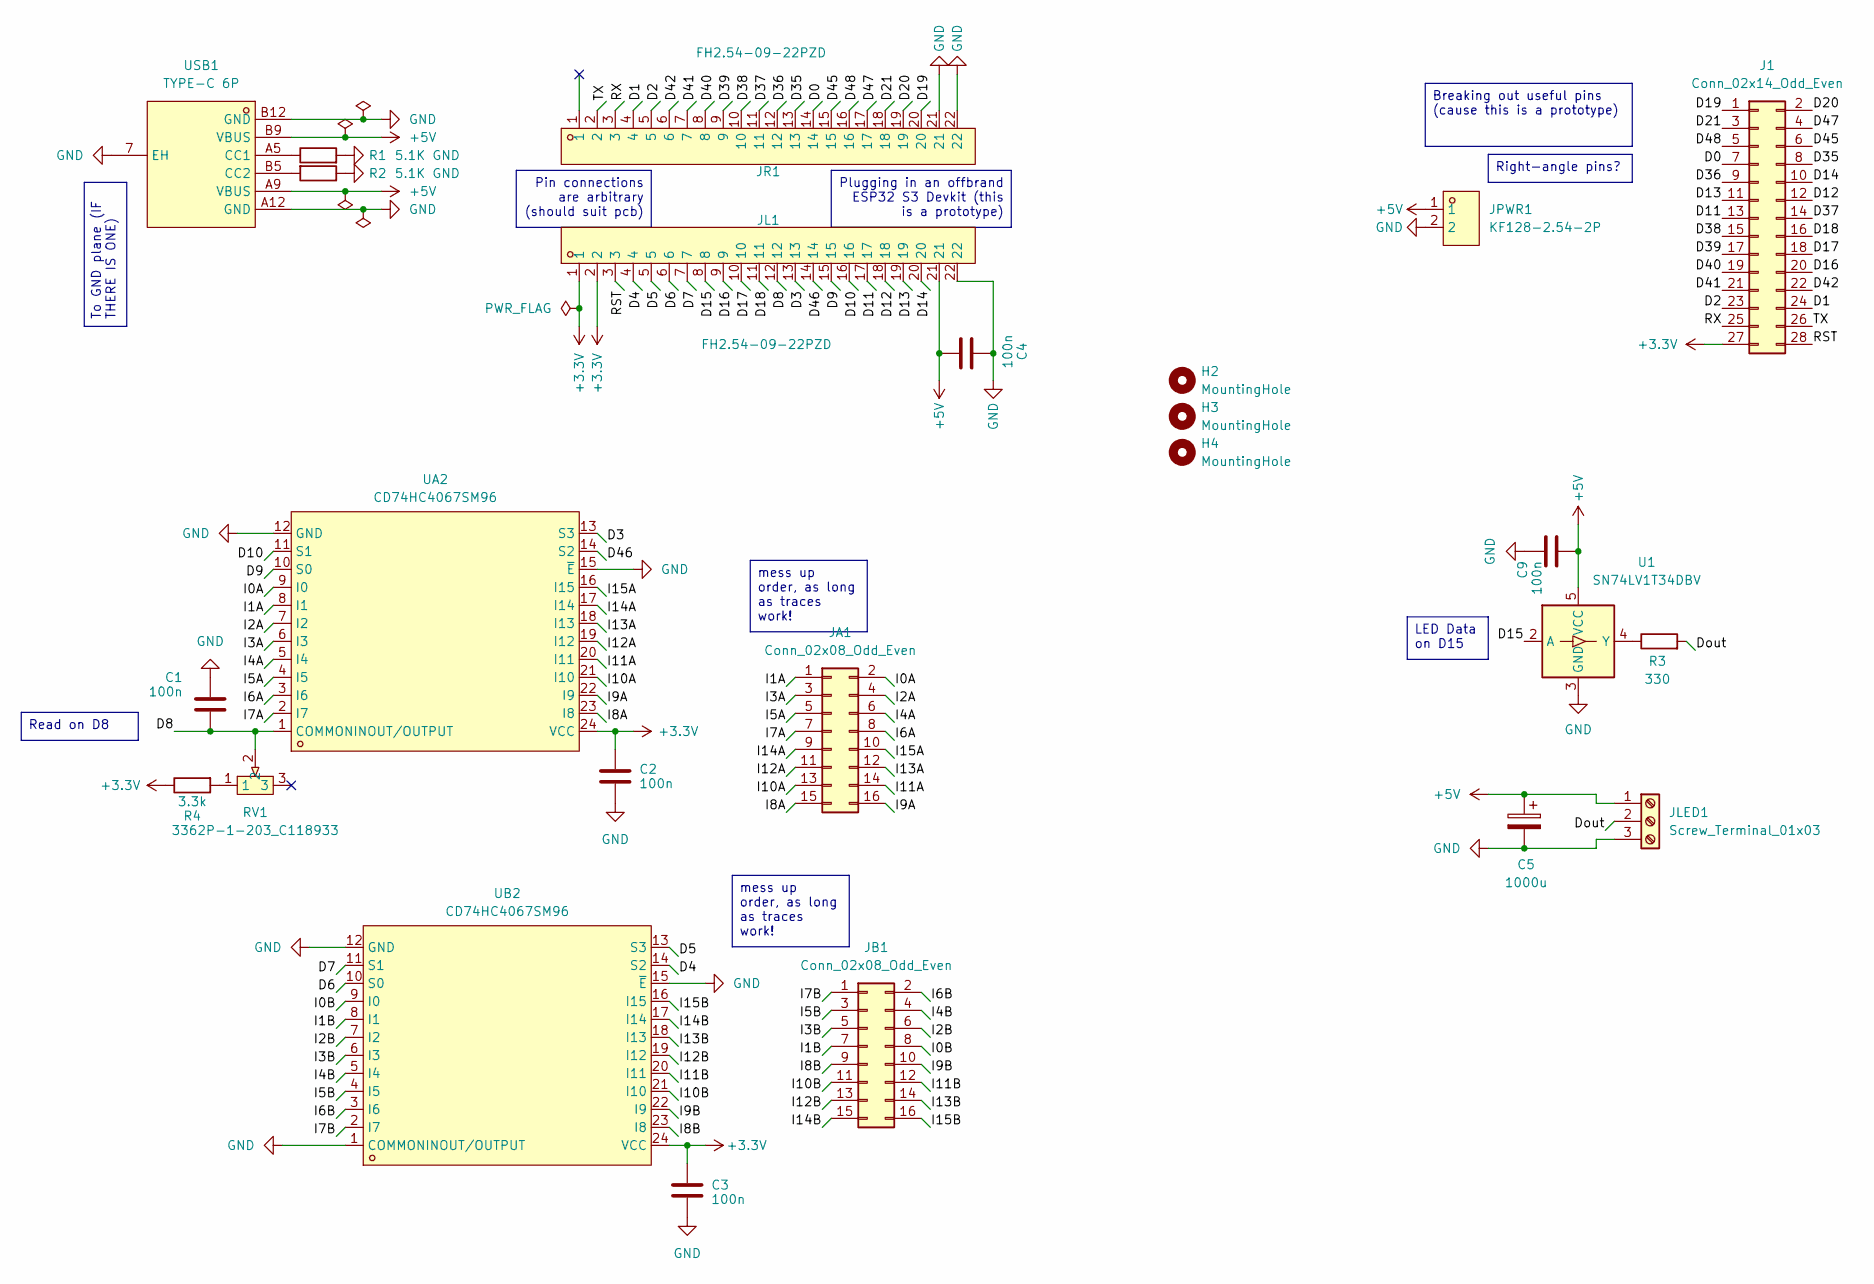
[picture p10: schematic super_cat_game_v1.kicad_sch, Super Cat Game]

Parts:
C1, C2, C3, C9: 100n; C_0805_2012Metric_Pad1.18x1.45mm_HandSolder; JLC_3DModel 32fe2cf9314f444ca2785a33c2db7189
C4: 100n; C_0805_2012Metric_Pad1.18x1.45mm_HandSolder; LCSC Part C28233
C5: 1000u; cap_flat; JLC_3DModel fb7e59b4bf4a464e9052b6d7cde2fdda
H2, H3, H4: MountingHole; MountingHole_3.2mm_M3
J1: Conn_02x14_Odd_Even; HDR-TH_28P-P2.54-H-M-R2-C14-S2.54; LCSC Part C725926
JA1: Conn_02x08_Odd_Even; IDC-TH_16P-P2.54_C3406; JLC_3DModel 20dc7cf4168b42d3ab78a2412575e9e9
JB1: Conn_02x08_Odd_Even; IDC-TH_16P-P2.54_C3406; JLC_3DModel 20dc7cf4168b42d3ab78a2412575e9e9
JL1: FH2.54-09-22PZD; HDR-TH_22P-P2.54-V-M; MPN FH2.54-09-22PZD; LCSC Part C7500786
JLED1: Screw_Terminal_01x03; CONN-TH_3P-P2.54_KF128-2.54-3P; JLC_3DModel a3f15aa9d36b4fa2b870b9dbfce89390
JPWR1: KF128-2.54-2P; CONN-TH_P2.54_KF128-2.54-2P; MPN KF128-2.54-2P; LCSC Part C474920
JR1: FH2.54-09-22PZD; HDR-TH_22P-P2.54-V-M; MPN FH2.54-09-22PZD; LCSC Part C7500786
R1, R2: 5.1K; R_0805_2012Metric_Pad1.20x1.40mm_HandSolder; LCSC Part C27834
R3: 330; R_0805_2012Metric_Pad1.20x1.40mm_HandSolder; LCSC Part C17630
R4: 3.3k; R_0805_2012Metric_Pad1.20x1.40mm_HandSolder; LCSC Part C26020
RV1: 3362P-1-203_C118933; RES-ADJ-TH_3P-L7.1-W6.9-P2.50-L_3362P; MPN 3362P-1-203; LCSC Part C118933
U1: SN74LV1T34DBV; SOT-23-5_HandSoldering; LCSC Part C100024
UA2: CD74HC4067SM96; SSOP-24_L8.1-W5.3-P0.65-LS7.8-BL; MPN CD74HC4067SM96; LCSC Part C98457
UB2: CD74HC4067SM96; SSOP-24_L8.1-W5.3-P0.65-LS7.8-BL; MPN CD74HC4067SM96; LCSC Part C98457
USB1: TYPE-C 6P; TYPE-C-SMD_TYPE-C-6P_1; MPN TYPE-C 6P; LCSC Part C456012

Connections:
+3.3V: C2.1, C3.1, J1.27, JL1.1, JL1.2, R4.1, UA2.24 (VCC), UB2.24 (VCC)
+5V: C4.2, C5.1, C9.1, JL1.21, JLED1.1, JPWR1.1, U1.5 (VCC), USB1.A9 (VBUS), USB1.B9 (VBUS)
/D0: J1.7, JR1.14
/D1: J1.24, JR1.4
/D2: J1.23, JR1.5
/D3: JL1.13, UA2.13 (S3)
/D4: JL1.4, UB2.14 (S2)
/D5: JL1.5, UB2.13 (S3)
/D6: JL1.6, UB2.10 (S0)
/D7: JL1.7, UB2.11 (S1)
/D8: C1.1, JL1.12, RV1.2, UA2.1 (COMMONINOUT/OUTPUT)
/D9: JL1.15, UA2.10 (S0)
/D10: JL1.16, UA2.11 (S1)
/D11: J1.13, JL1.17
/D12: J1.12, JL1.18
/D13: J1.11, JL1.19
/D14: J1.10, JL1.20
/D15: JL1.8, U1.2 (A)
/D16: J1.20, JL1.9
/D17: J1.18, JL1.10
/D18: J1.16, JL1.11
/D19: J1.1, JR1.20
/D20: J1.2, JR1.19
/D21: J1.3, JR1.18
/D35: J1.8, JR1.13
/D36: J1.9, JR1.12
/D37: J1.14, JR1.11
/D38: J1.15, JR1.10
/D39: J1.17, JR1.9
/D40: J1.19, JR1.8
/D41: J1.21, JR1.7
/D42: J1.22, JR1.6
/D45: J1.6, JR1.15
/D46: JL1.14, UA2.14 (S2)
/D47: J1.4, JR1.17
/D48: J1.5, JR1.16
/Dout: JLED1.2, R3.2
/I0A: JA1.2, UA2.9 (I0)
/I0B: JB1.8, UB2.9 (I0)
/I1A: JA1.1, UA2.8 (I1)
/I1B: JB1.7, UB2.8 (I1)
/I2A: JA1.4, UA2.7 (I2)
/I2B: JB1.6, UB2.7 (I2)
/I3A: JA1.3, UA2.6 (I3)
/I3B: JB1.5, UB2.6 (I3)
/I4A: JA1.6, UA2.5 (I4)
/I4B: JB1.4, UB2.5 (I4)
/I5A: JA1.5, UA2.4 (I5)
/I5B: JB1.3, UB2.4 (I5)
/I6A: JA1.8, UA2.3 (I6)
/I6B: JB1.2, UB2.3 (I6)
/I7A: JA1.7, UA2.2 (I7)
/I7B: JB1.1, UB2.2 (I7)
/I8A: JA1.15, UA2.23 (I8)
/I8B: JB1.9, UB2.23 (I8)
/I9A: JA1.16, UA2.22 (I9)
/I9B: JB1.10, UB2.22 (I9)
/I10A: JA1.13, UA2.21 (I10)
/I10B: JB1.11, UB2.21 (I10)
/I11A: JA1.14, UA2.20 (I11)
/I11B: JB1.12, UB2.20 (I11)
/I12A: JA1.11, UA2.19 (I12)
/I12B: JB1.13, UB2.19 (I12)
/I13A: JA1.12, UA2.18 (I13)
/I13B: JB1.14, UB2.18 (I13)
/I14A: JA1.9, UA2.17 (I14)
/I14B: JB1.15, UB2.17 (I14)
/I15A: JA1.10, UA2.16 (I15)
/I15B: JB1.16, UB2.16 (I15)
/RST: J1.28, JL1.3
/RX: J1.25, JR1.3
/TX: J1.26, JR1.2
GND: C1.2, C2.2, C3.2, C4.1, C5.2, C9.2, JL1.22, JLED1.3, JPWR1.2, JR1.21, JR1.22, R1.2, R2.1, U1.3 (GND), UA2.12 (GND), UA2.15 (~E), UB2.1 (COMMONINOUT/OUTPUT), UB2.12 (GND), UB2.15 (~E), USB1.7 (EH), USB1.A12 (GND), USB1.B12 (GND)
unnamed: R4.2, RV1.1
unnamed: R3.1, U1.4 (Y)
unnamed: R1.1, USB1.A5 (CC1)
unnamed: R2.2, USB1.B5 (CC2)

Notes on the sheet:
To GND plane (IF THERE IS ONE)
mess up order, as long as traces work!
Breaking out useful pins (cause this is a prototype)
Read on D8
Right-angle pins?
Plugging in an offbrand ESP32 S3 Devkit (this is a prototype)
LED Data on D15
Pin connections are arbitrary (should suit pcb)

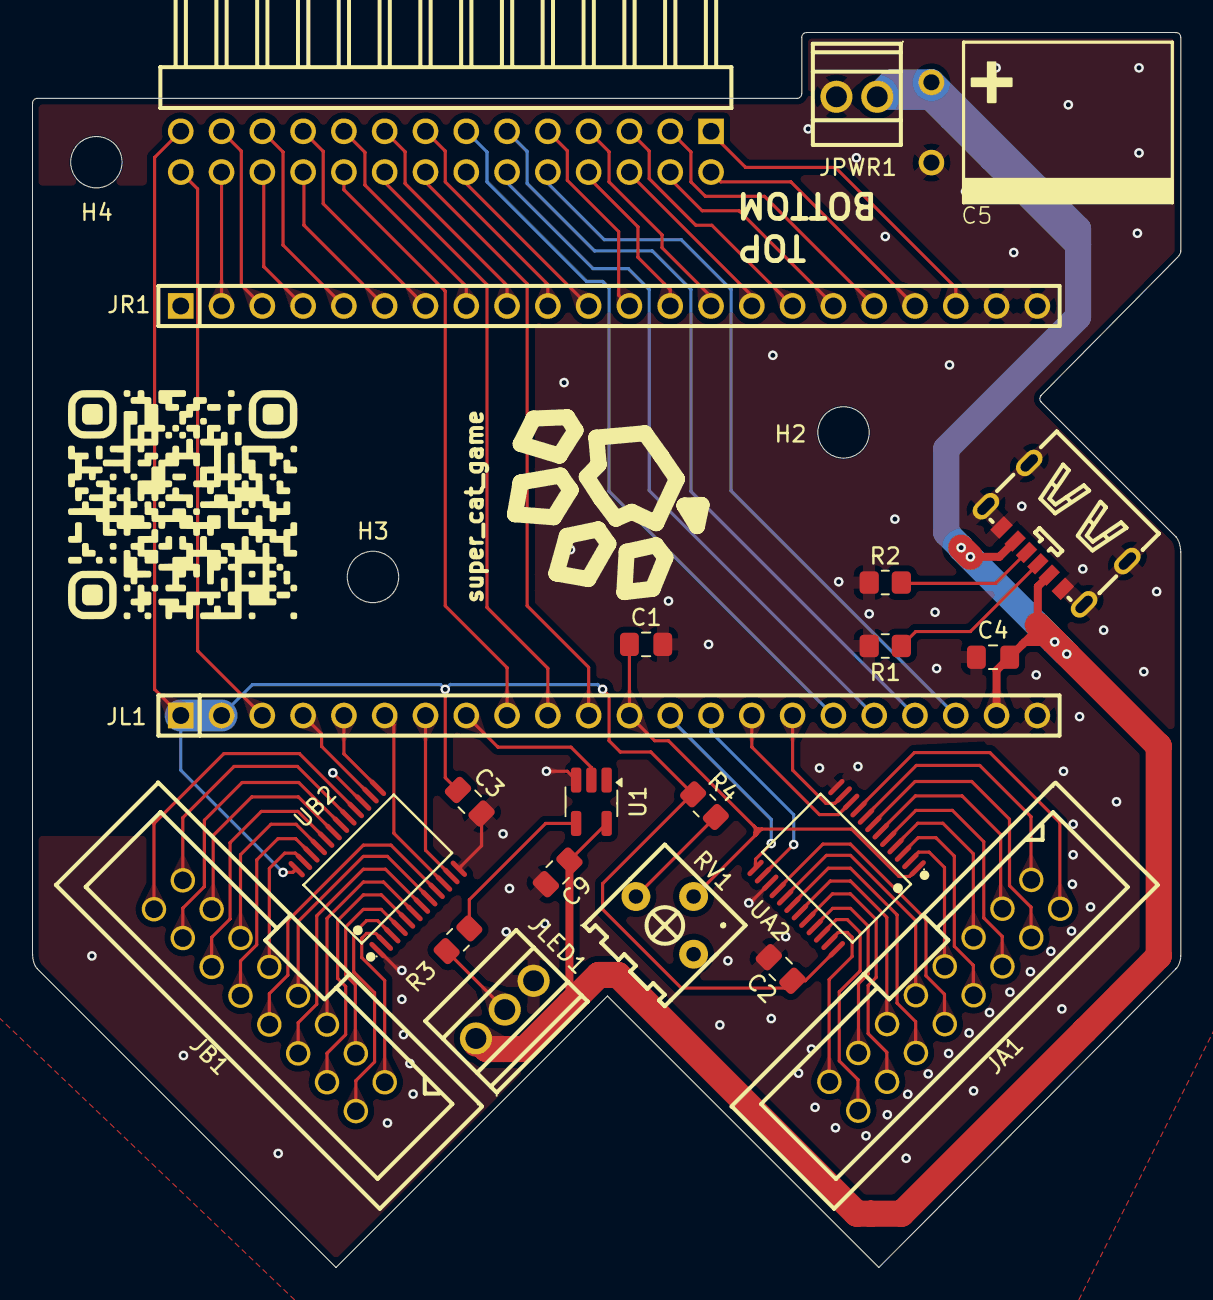
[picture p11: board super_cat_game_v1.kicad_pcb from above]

Board: 2 copper layers, 71.5 x 76.9 mm, 25 parts (0 on the bottom side), 77 nets.

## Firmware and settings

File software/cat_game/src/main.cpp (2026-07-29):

// hi! the main code is further below, at //// MAIN CODE ////
// the rest is functions and stuff that makes it work
// the functions I thought would be generally useful are in functions.cpp


#include <Arduino.h>
#include <FastLED.h>
#include "functions.h"


//// CAT GAME SETTINGS //// (the hardware settings are in ../include/functions.h)
#define MAX_J 0.001  // jerk in units/frame^3 (how fast the dot's acceleration changes)
#define SENSITIVITY 0.8 * 4095  // 0-1, the maximum resistance value considered as detected (max. is 4095 but in reality max. is less)
// lower reading means lower resistance so higher pressure, reading 0 when max. out pressure
// the pot on the PCB is a more robust adjustment? Voltage divider basically reads Rvelostat/Rtotal so lower (anticlockwise?) increases sensitivity


//// CAT GAME FUNCTIONS ////

// return true if the dot is caught
bool Caught(float x, float y, int Pressure_m[VELOSTAT_WIDTH][VELOSTAT_WIDTH]) {
  // detect if touching:
  // top left
  if ( Pressure_m[(int) floor(y * VELOSTAT_WIDTH)][(int) floor(x * VELOSTAT_WIDTH)] <= SENSITIVITY) {
    return true;
  }
  // top right
  if ( Pressure_m[(int) floor(y * VELOSTAT_WIDTH)][(int) ceil(x * VELOSTAT_WIDTH)] <= SENSITIVITY) {
    return true;
  }
  // bottom left
  if ( Pressure_m[(int) ceil(y * VELOSTAT_WIDTH)][(int) floor(x * VELOSTAT_WIDTH)] <= SENSITIVITY) {
    return true;
  }
  // bottom right
  if ( Pressure_m[(int) ceil(y * VELOSTAT_WIDTH)][(int) ceil(x * VELOSTAT_WIDTH)] <= SENSITIVITY) {
    return true;
  }
}

// choose a direction to move in, then return the jerk in that direction to the provided jx jy vector
void Set_jerk(float x, float y, float &jx, float &jy, int Pressure_m[VELOSTAT_WIDTH][VELOSTAT_WIDTH]) {

  // reset the jerk
  jx = 0;
  jy = 0;
  
  //// heuristic for choosing direction ////
  // move away from walls
  jx += 0.5 - x;
  jy += 0.5 - y;

  // move away from nearby pressed cells
  for (int Y=1; Y<=VELOSTAT_WIDTH; Y++) {
    for (int X=1; X<=VELOSTAT_WIDTH; X++) {

      if (Pressure_m[Y][X] <= SENSITIVITY) {  // if cell is pressed
        jx += (X/VELOSTAT_WIDTH - x) - 1;
        jy += (Y/VELOSTAT_WIDTH - y) - 1;
      }
    }
  }

  //// scale the jerk so it has magnitude MAX_J ////
  float mag = sqrt(jx*jx + jy*jy);
  jx == jx / mag * MAX_J;
  jy == jy / mag * MAX_J;

}

// add instructions to light up the 4 LEDs nearest to the dot with 1/4 brightness (but they can overlap too...)
void Draw_dot(float x, float y, CRGB* LED_m[LED_WIDTH][LED_WIDTH]) {
  *LED_m[(int)floor(y*LED_WIDTH)][(int)floor(x*LED_WIDTH)] += CRGB(225/4,0,0);  // add 1/4 brightness red to top-left pixel
  *LED_m[(int)ceil(y*LED_WIDTH)][(int)floor(x*LED_WIDTH)] += CRGB(225/4,0,0);  // add 1/4 brightness red to top-right pixel
  *LED_m[(int)floor(y*LED_WIDTH)][(int)ceil(x*LED_WIDTH)] += CRGB(225/4,0,0);  // add 1/4 brightness red to bottom-left pixel
  *LED_m[(int)ceil(y*LED_WIDTH)][(int)ceil(x*LED_WIDTH)] += CRGB(225/4,0,0);  // add 1/4 brightness red to bottom-right pixel
}

void Draw_caught_dot(float x, float y, CRGB* LED_m[LED_WIDTH][LED_WIDTH]) {
  *LED_m[(int)floor(y*LED_WIDTH)][(int)floor(x*LED_WIDTH)] += CRGB(225/4,0,0);  // add 1/4 brightness red to top-left pixel
  *LED_m[(int)ceil(y*LED_WIDTH)][(int)floor(x*LED_WIDTH)] += CRGB(225/4,0,0);  // add 1/4 brightness red to bottom-left pixel
  *LED_m[(int)floor(y*LED_WIDTH)][(int)ceil(x*LED_WIDTH)] += CRGB(225/4,0,0);  // add 1/4 brightness red to top-right pixel
  *LED_m[(int)ceil(y*LED_WIDTH)][(int)ceil(x*LED_WIDTH)] += CRGB(225/4,0,0);  // add 1/4 brightness red to bottom-right pixel

  // draw extra stuff, like a cross so you know the dot has been caught
  try {*LED_m[(int)floor(y*LED_WIDTH) -1][(int)floor(x*LED_WIDTH) -1] += CRGB(225/4,0,0);}// add 1/4 brightness red to far top-left pixel
  catch(...) {}  
  try {*LED_m[(int)ceil(y*LED_WIDTH) +1][(int)floor(x*LED_WIDTH) -1] += CRGB(225/4,0,0);}  // add 1/4 brightness red to far bottom-left pixel
  catch(...) {} 
  try {*LED_m[(int)floor(y*LED_WIDTH) -1][(int)ceil(x*LED_WIDTH) +1] += CRGB(225/4,0,0);}  // add 1/4 brightness red to far top-right pixel
  catch(...) {} 
  try {*LED_m[(int)ceil(y*LED_WIDTH) +1][(int)ceil(x*LED_WIDTH) +1] += CRGB(225/4,0,0);}  // add 1/4 brightness red to far bottom-right pixel
  catch(...) {} 

}

// call this to restart the code
void(* Reset) (void) = 0;

//// MAIN CODE ////

//// hardware variables ////
// LEDs
CRGB LEDs[NUM_LEDS];  // Linear array representing LED strip
CRGB* LED_m[LED_WIDTH][LED_WIDTH];  // LED matrix (will be reorganised from ^ linear array)
// LED_m[Y][X]

int Pressure_m[VELOSTAT_WIDTH][VELOSTAT_WIDTH];  // array of arrays storing pressure readings for the board
// Pressure_m[y][x] for the pressure reading at (x,y)

//// cat game variables ////
// position in proportion_of_screen
float x;  // (0-1, where 0 is far left and 1 is far right)
float y;  // (0-1, where 0 is far top and 1 is far bottom)
 
// velocity in proportion_of_screen/loop_time (loop_time is the time taken for a loop to run)
float vx;
float vy; 

// acceleration in proportion_of_screen/loop_time^2
float ax;
float ay; 

// jerk in proportion_of_screen/loop_time^3
float jx;
float jy;

void setup() {
  // put your setup code here, to run once:
  init_LED_ptrs(LED_m, LEDs);
  FastLED.addLeds<NEOPIXEL, LED_PIN>(LEDs, NUM_LEDS);
  FastLED.setMaxPowerInVoltsAndMilliamps(5, 2500);

  // acceleration in proportion_of_screen/loop_time^2
  ax = 0;
  ay = 0;

  // initally 0 velocity
  vx=0;
  vy=0;
  
  // initial position in the middle
  x=0.5;
  y=0.5;
  
}

void loop() {
  // put your main code here, to run repeatedly:
  // "*(LED_m[Y][X]) = CRGB:: " to set CRGB of LEDs

  Read_pressure_all(Pressure_m);  // read pressure at the start of every loop

  if (Caught(x, y, Pressure_m)) {
    // blink dot 5 times
    for (int i; i<5; i++) {

      //// add instructions to draw the caught dot ////
      fill_solid(LEDs, NUM_LEDS, CRGB::Black);  // reset all LEDs first
      FastLED.show();  

      delay(500);

      Draw_caught_dot(x, y, LED_m);  // draw the dot
      FastLED.show();  

      delay(500);

    }

    Reset();

  }
  else {

    Set_jerk(x, y, jx, jy, Pressure_m);  // choose desired direction and set jerk in that direction
  
    //// move in the chosen direction ////
    // jerk, always using the maximum amount
    ax += jx;
    ay += jy;

    // accelerate
    vx += ax;
    vy += ay;

    // displace
    x += vx;
    y += vy;

    //// add instructions to draw the dot ////
    fill_solid(LEDs, NUM_LEDS, CRGB::Black);  // reset all LEDs first
    Draw_dot(x, y, LED_m);  // draw the dot
  }

  

  // end of main code


  FastLED.show();  // send the instructions to the LEDs every loop
}

///////////////////////////////////////////////////////////////////////////////////////////////////////////////////////////////////////

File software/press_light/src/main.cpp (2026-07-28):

#include <Arduino.h>
#include <FastLED.h>

#define SENSITIVITY 0.8  // 0-1, the proportion of maximum pressure range considered detected (max. is 4095 but in reality max. is less)
// lower reading means lower resistance so higher pressure, reading 0 when max. out pressure
// the pot on the PCB is a more robust adjustment? Voltage divider basically reads Rvelostat/Rtotal so lower (anticlockwise?) increases sensitivity
#define VELOSTAT_WIDTH 14
#define LED_WIDTH 13
#define NUM_LEDS 169

#define LED_PIN 15

#define S0a 9
#define S1a 10
#define S2a 46
#define S3a 3

#define S0b 6
#define S1b 7
#define S2b 4
#define S3b 5

//LEDs
CRGB LEDs[NUM_LEDS];  // LED strip for FastLED
CRGB* LED_m[LED_WIDTH][LED_WIDTH];  // LED matrix (reorganised from linear array)
// LED_m[Y][X]


// mapping out velostat channels
const int Channel_m[2][16] = {
  {1,0,3,2,5,4,7,6,14,15,12,13,10,11,8,9},
  {7,6,5,4,3,2,1,0,8,9,10,11,12,13,14,15}
};  // Set A (x) followed by Set B (y)
// (0,0) is top left; Y goes down, X goes right
// matrices follow Matrix[Y][X]



int Pressure_m[VELOSTAT_WIDTH][VELOSTAT_WIDTH];




void Read_pressure(int Pressure_m[VELOSTAT_WIDTH][VELOSTAT_WIDTH]) {
  int Channel;

  for (int Y=0; Y<VELOSTAT_WIDTH; Y+=1) {

    Channel = Channel_m[1][Y];
    digitalWrite(S0b, Channel & 0x01);
    digitalWrite(S1b, (Channel >> 1) & 0x01);
    digitalWrite(S2b, (Channel >> 2) & 0x01);
    digitalWrite(S3b, (Channel >> 3) & 0x01);

    for (int X=0; X<VELOSTAT_WIDTH; X+=1) {

      Channel = Channel_m[0][X];
      digitalWrite(S0a, Channel & 0x01);
      digitalWrite(S1a, (Channel >> 1) & 0x01);
      digitalWrite(S2a, (Channel >> 2) & 0x01);
      digitalWrite(S3a, (Channel >> 3) & 0x01);

      Pressure_m[Y][X] = analogRead(A0);

    }
  }
}

void init_LED_ptrs(CRGB* LED_m[LED_WIDTH][LED_WIDTH], CRGB LEDs[NUM_LEDS]) {
  // map LED_m to the right spots in LEDs
  
  bool right = true;

  for (int Y=0; Y<LED_WIDTH; Y+=1) {
    
    for (int X=0; X<LED_WIDTH; X+=1) {

      if(right = true) {
        right = false;

        //set pixels, moving right
        LED_m[Y][X] = &LEDs[Y*LED_WIDTH + X];

      }
      else {
        right = true;

        //set pixels, moving left
        LED_m[Y][X] = &LEDs[(Y+1)*LED_WIDTH - X - 1];

      }

    }
    
    // change direction when changing rows
    if(right = true) {
      right = false;
    }
    else {
      right = true;
    }

  }

}






///////////////////////////////////////////////////////////////////////////////////////////////////////////////

void setup() {
  // put your setup code here, to run once:
  init_LED_ptrs(LED_m, LEDs);
  FastLED.addLeds<NEOPIXEL, LED_PIN>(LEDs, NUM_LEDS);
  FastLED.setMaxPowerInVoltsAndMilliamps(5, 2500);
}

void loop() {
  Read_pressure(Pressure_m);
  // put your main code here, to run repeatedly:
  // "*(LED_m[Y][X]) = " to set CRGB of LEDs

  // press test V0:
  //  - using velostat intersections as the coordinates, so a 14*14 grid
  //  - light up the LEDs adjacent to detected (low resistance)

  fill_solid(LEDs, NUM_LEDS, CRGB::Black);  // reset all LEDs before drawing

  // for every cell:
  for (int Y=0; Y<VELOSTAT_WIDTH; Y+=1) {
    for (int X=0; X<VELOSTAT_WIDTH; X+=1) {
      if (Pressure_m[Y][X] < 4095*SENSITIVITY) {  // if the cell is pressed enough,
        // light up the LEDs around it (n and n+1) (x,y)
        *LED_m[Y][X] = CRGB::Red;
        *LED_m[Y+1][X] = CRGB::Red;
        *LED_m[Y][X+1] = CRGB::Red;
        *LED_m[Y+1][X+1] = CRGB::Red;
        // the * changes the LEDs value corresponding to the LED_m value

      }
    }
  }



  FastLED.show();
}

///////////////////////////////////////////////////////////////////////////////////////////////////////////////////////////////////////

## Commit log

2026-07-02 Revise README with project updates and details
    Updated project description and added details about the PCB model and game potential.
2026-07-02 V0 kicad project
    [2xcounter_circuit.kicad_sch, circuit.kicad_sch, counter_circuit.kicad_sch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]
2026-07-02 Create kicad project v0
2026-07-04 added local files so far
    before I was doing everything locally without any version control, so here I just copy-pasted all that mess into the repo
    [.step, 2xcounter_circuit.kicad_sch, C82004.step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]
2026-07-04 gitignore and removed unnecessary old files
    there was old stuff about emr tech and stuff, dw i saved it locally for another project
    also I added .gitignore for the kicad backups and stuff
    [2xcounter_circuit.kicad_sch, bom.csv, circuit.kicad_sch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]
2026-07-04 renamed kicad-project folder
    remember, the pcb works now, but it's super overpriced, so I'm gonna try to make it cheaper (before I've already given the usb port extra clearance on the sides)
    [.step, 2xcounter_circuit.kicad_sch, C82004.step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]
2026-07-05 cleaning up footprints
    used easyeda2kicad.py to get better footprints (with 3d models) (https://github.com/uPesy/easyeda2kicad.py)
    it's kinda messy bc some symbols are kicad and others easyeda, shouldn't matter tho (e.g. on C6 can't see the 470u value, only part ref)
    [pressure_sense.kicad_pcb, pressure_sense.kicad_sch]
2026-07-05 changed capacitor for cost
    the two smd caps cost extra $6 just for the toolhead! I changed it to one tht that is hand-soldered (the leads need to be bent)
    [EEU-HD1H102B.STEP, pressure_sense.kicad_pcb, pressure_sense.kicad_sch]
2026-07-05 production files processed, and keep out zone added
    going through the jlcpcb order process, adjusting cpl (positions) and checking the price
    JLCPCB Fabrication Toolkit doesn't listen to my selection of "exclude from pick and place file" for mounting holes, so I had to delete them manually
    [bom.csv, designators.csv, positions.csv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]
2026-07-06 Update README with future improvements and warnings
    Added a section on future improvements and clarified warnings regarding KICAD production files.
2026-07-06 changed usbc port
    the port had tiny pads, i changed it for a less dodgy 6p one cause I don't need data
    dw I adjusted positions.csv
    [EEU-HD1H102B.STEP, board.step, bom.csv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]
2026-07-06 oops forgot the 3d model
    i generated new 3d model
    [board.step]
2026-07-15 BIG CHANGE TO PCB
    So since there's actually more time on Fallout, I decided to make the schematic simpler (so it's cheaper and smaller) by removing the uneccesary 74hc163 counters (there's plenty of gpio!)
    [pressure_sense.kicad_pcb, pressure_sense.kicad_sch]
2026-07-15 Oops, fixing the production files
    I forgot to update the production files, and since I'm not going to do PCBA anymore, I deleted the pick-and-place file... the BOM should now be correct tho!
    [bom.csv, designators.csv, positions.csv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]
2026-07-16 Update link to 3D-printed case on Onshape
2026-07-16 JLCPCB DFM check
    modifications to mostly satisfy JLCPCB's DFM check
    [boardV0.step, boardV1.step, pressure_sense.kicad_pcb]
2026-07-20 Enhance assembly instructions and resource links (not finished)
    Updated README with additional details on assembly, including links to resources and product recommendations.
2026-07-21 Revise README for clarity and additional information
    Updated README.md to enhance project details, including assembly instructions, firmware instructions, and future improvements.
2026-07-21 Update README to reflect Arduino sketches location
2026-07-21 Adding arduino code
    setting up arduino code folders, with local libraries
    [.step, 2xcounter_circuit.kicad_sch, boardV0.step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]
2026-07-21 removed old arduino file
    now using platformio ide in vs code
2026-07-28 Revise README for clarity on design and assembly
    Updated README to clarify design features and assembly instructions.
2026-07-29 added arduino sketch template with ArduinoOTA
2026-08-05 added overall bom and documented code
    [bom.csv, boxV1 - Bottom.step, boxV1 - Bottom.stl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]
2026-08-11 more README with BOM and stuff (not finished )
2026-08-12 updated BOM
    [bom.csv]
2026-08-12 added the LED wire to BOM
    [bom.csv]
2026-08-12 add info about velostat circuit to README
2026-08-12 Update README with sensor tiling image and description
    Added an image and a description of sensor tiling to the README.
2026-08-12 Update README with new images and sensor details
    Updated image references and clarified sensor matrix description.
2026-08-12 info on PSU
    [bom.csv]
2026-08-12 Clarify velostat matrix connection details in README
    Updated the README to clarify details about the velostat matrix connection and added a reference to the assembly walkthrough.
2026-10-03 organised kicad files, with a separate V0
    [.step, 2xcounter_circuit.kicad_sch, boardV0.step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]
2026-10-03 Enhance README with PCB and schematic images
    Updated PCB image and added schematic image to README.
    Also I added a bit about the kicad V0/V1
    btw I think fixed the 3D preview in kicad for the loaded PCBs
2026-10-03 Update README with notes on kicad_V0 design changes
    Added caution note regarding the V0 design and explained changes made to preserve GPIO pins.
2026-10-03 Clarify design choices and future suggestions in README
    Updated the README to clarify the design choices for kicad_V0 and V1, including the use of counter ICs for GPIO pin preservation and subsequent removal for efficiency. Added suggestions for future im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
2026-10-04 cleaned up the kicad projects
    [boardV0.step, boardV1.step, pressure_sense.kicad_pcb]
2026-10-04 cleaned up some more, updated README to reflect
    [.step, bom.csv, designators.csv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]
2026-10-04 cleaned up some more
    [.step, bom.csv, designators.csv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]
2026-10-04 Update README with new images for V0 and PCB
    Added additional images for V0 and V0 PCB in the README.
